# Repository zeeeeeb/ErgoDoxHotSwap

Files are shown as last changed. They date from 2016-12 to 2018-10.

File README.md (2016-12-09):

# Information
This repo is for the ErgoDox Mechanical Keyboard pcb and Litster's acrylic case designs (both standard and full hand).

## Changelog: 
2016-12-01: Updated with fixes to include proper support for 1u keys in the outer columns. Silkscreen updated to reflect ErgoDox.io as the new home of the ErgoDox. Removed unnessicary .hex files and teensy.dmg files. 

**See our [Releases](https://github.com/Ergodox-io/ErgoDox/releases) for details**

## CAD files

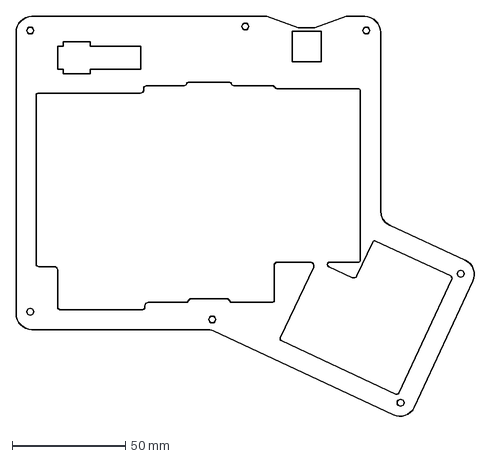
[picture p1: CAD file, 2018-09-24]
ErgoDox Acrylic Case/ErgoDOX Acrylic Case - Designed by Litster/Standard/Left/ErgoDOX Case Layer 2 Spacer - Left.dxf
202.8 x 177.8 mm

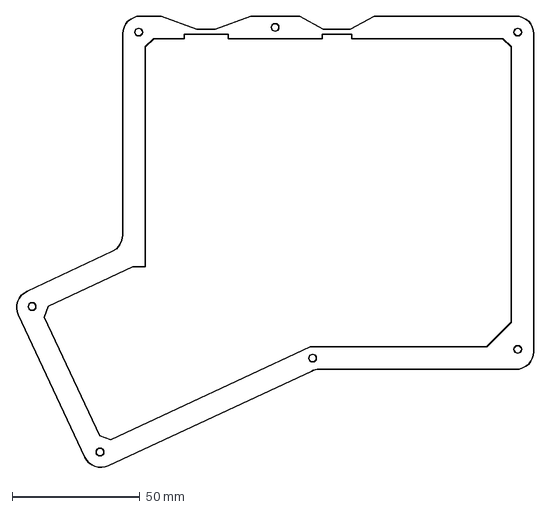
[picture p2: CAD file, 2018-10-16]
ErgoDox Acrylic Case/ErgoDOX Acrylic Case - Designed by Litster/Standard/Right/ErgoDOX Case Layer 4 Spacer - Right.dxf
202.8 x 177.8 mm

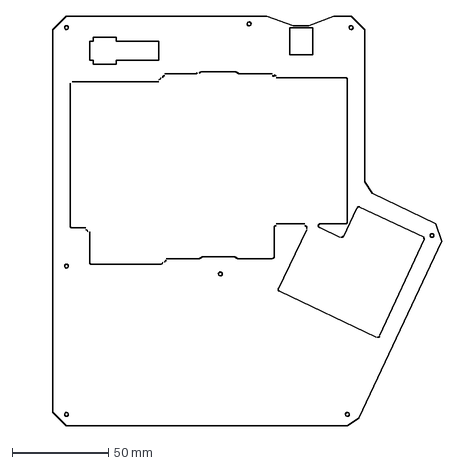
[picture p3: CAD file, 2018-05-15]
ErgoDox Acrylic Case/ErgoDOX Acrylic Case - Designed by Litster/with Wrist Rest/Left/ErgoDOX Case Layer 2 Spacer - Left.dxf
221.0 x 213.0 mm

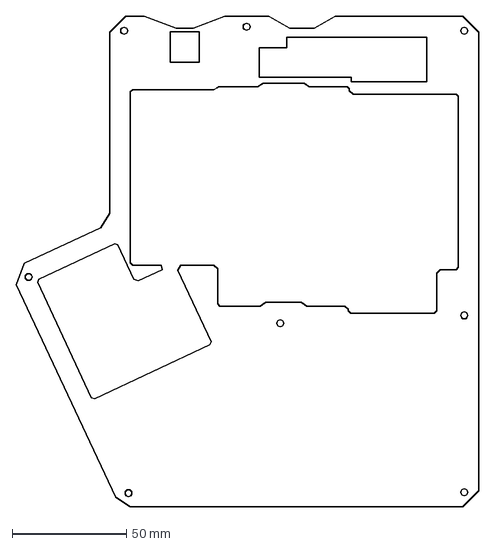
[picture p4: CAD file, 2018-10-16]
ErgoDox Acrylic Case/ErgoDOX Acrylic Case - Designed by Litster/with Wrist Rest/Right/ErgoDOX Wrist Rest Case Layer 2 Spacer - Right.dxf
202.0 x 214.1 mm

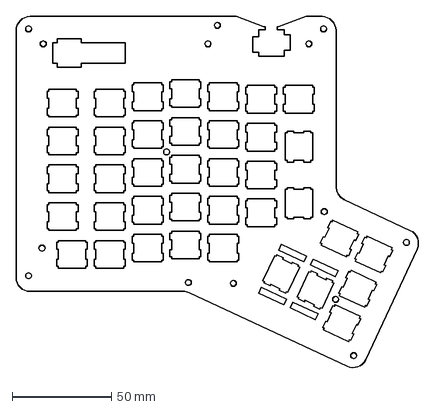
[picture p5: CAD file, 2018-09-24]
ErgoDox Acrylic Case/ErgoDOX Acrylic Case - Designed by Litster/Standard/Left/ErgoDOX Case Layer 3 Plate - Left.dxf
202.8 x 177.8 mm

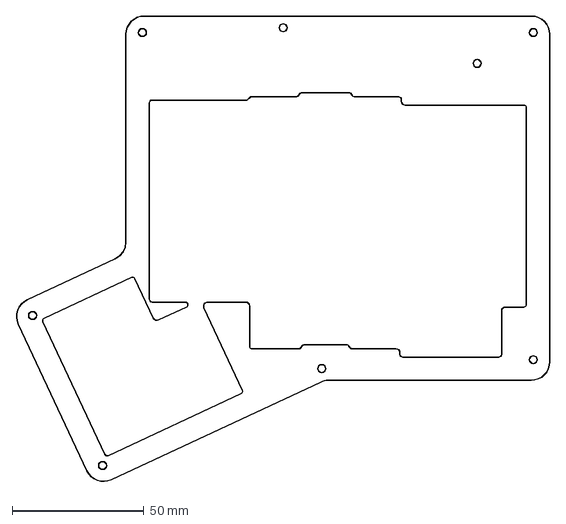
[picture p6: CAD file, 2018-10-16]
ErgoDox Acrylic Case/ErgoDOX Acrylic Case - Designed by Litster/Standard/Right/ErgoDOX Case Layer 1 Top - Right.dxf
202.8 x 177.8 mm

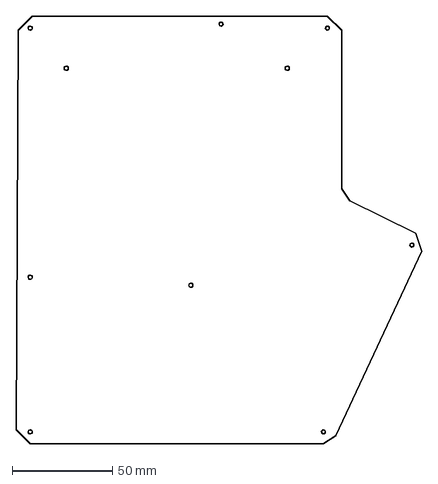
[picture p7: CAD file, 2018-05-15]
ErgoDox Acrylic Case/ErgoDOX Acrylic Case - Designed by Litster/with Wrist Rest/Left/ErgoDOX Case Layer 5 Bottom - Left.dxf
202.0 x 213.0 mm

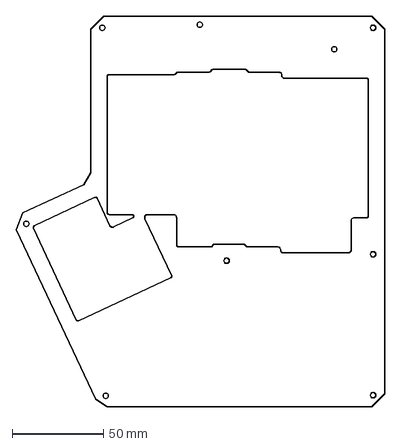
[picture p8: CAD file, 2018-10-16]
ErgoDox Acrylic Case/ErgoDOX Acrylic Case - Designed by Litster/with Wrist Rest/Right/ErgoDOX Wrist Rest Case Layer 1 Top - Right.dxf
202.0 x 214.1 mm

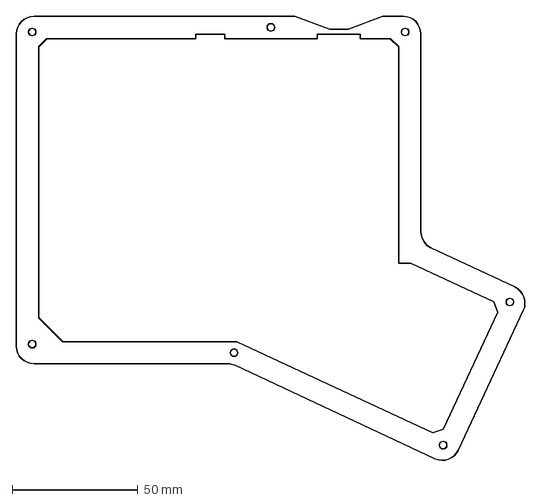
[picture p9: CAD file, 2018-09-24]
ErgoDox Acrylic Case/ErgoDOX Acrylic Case - Designed by Litster/Standard/Left/ErgoDOX Case Layer 4 Spacer - Left.dxf
202.8 x 177.8 mm

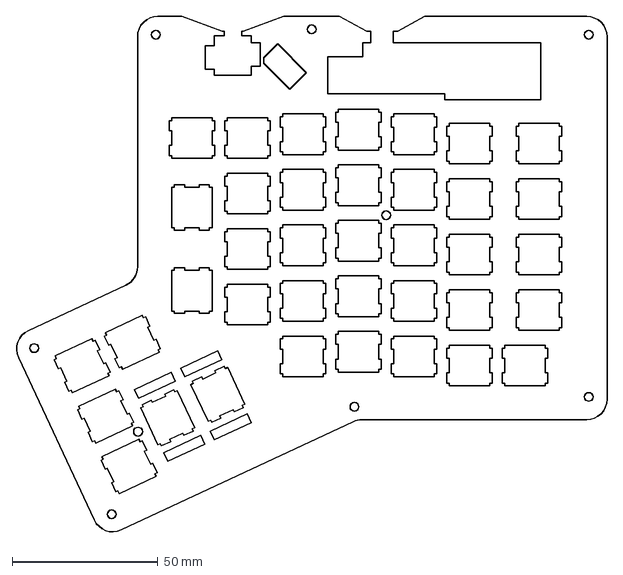
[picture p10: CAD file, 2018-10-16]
ErgoDox Acrylic Case/ErgoDOX Acrylic Case - Designed by Litster/Standard/Right/ErgoDOX Case Layer 3 Plate - Right.dxf
202.8 x 177.8 mm

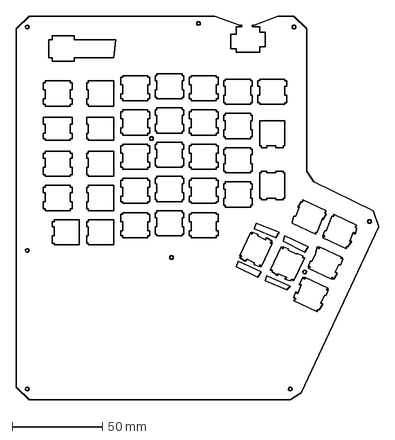
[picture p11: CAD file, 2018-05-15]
ErgoDox Acrylic Case/ErgoDOX Acrylic Case - Designed by Litster/with Wrist Rest/Left/ErgoDOX Case Layer 3 Plate - Left.dxf
201.0 x 213.0 mm

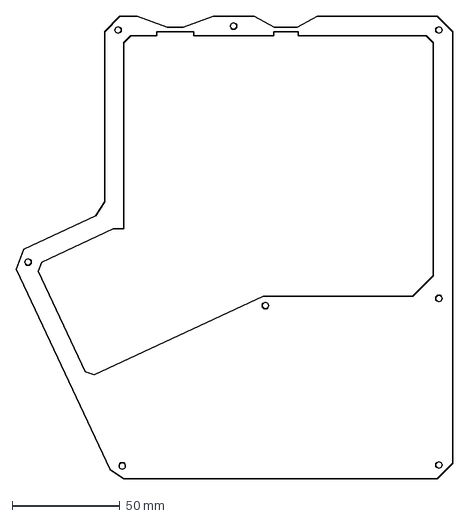
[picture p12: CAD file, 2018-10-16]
ErgoDox Acrylic Case/ErgoDOX Acrylic Case - Designed by Litster/with Wrist Rest/Right/ErgoDOX Wrist Rest Case Layer 4 Spacer - Right.dxf
202.0 x 214.1 mm

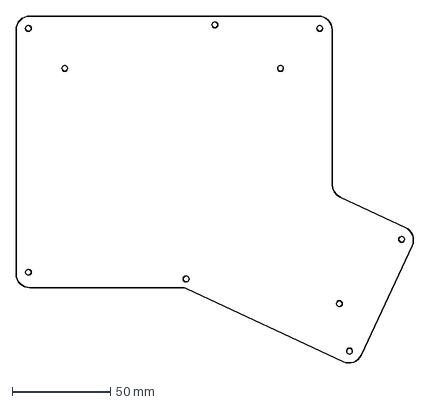
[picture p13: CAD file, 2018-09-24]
ErgoDox Acrylic Case/ErgoDOX Acrylic Case - Designed by Litster/Standard/Left/ErgoDOX Case Layer 5 Bottom - Left.dxf
202.8 x 177.8 mm

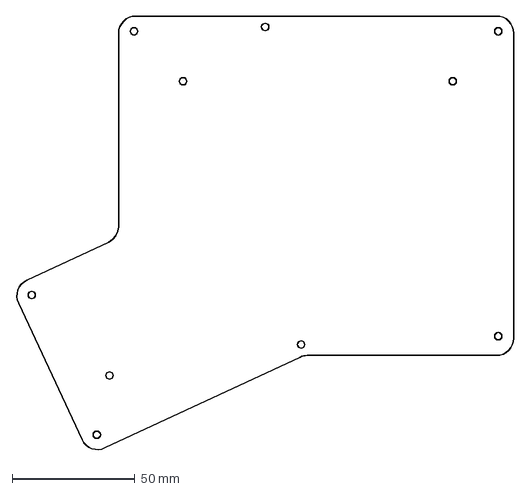
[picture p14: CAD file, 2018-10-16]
ErgoDox Acrylic Case/ErgoDOX Acrylic Case - Designed by Litster/Standard/Right/ErgoDOX Case Layer 5 Bottom - Right.dxf
202.8 x 177.8 mm

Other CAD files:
ErgoDox Acrylic Case/ErgoDOX Acrylic Case - Designed by Litster/with Wrist Rest/Left/ErgoDOX Case Layer 1 Top - Left.dxf
ErgoDox Acrylic Case/ErgoDOX Acrylic Case - Designed by Litster/with Wrist Rest/Right/ErgoDOX Wrist Rest Case Layer 3 Plate - Right.dxf
ErgoDox Acrylic Case/ErgoDOX Acrylic Case - Designed by Litster/Standard/Left/ErgoDOX Case Layer 1 Top - Left.dxf
ErgoDox Acrylic Case/ErgoDOX Acrylic Case - Designed by Litster/Standard/Right/ErgoDOX Case Layer 2 Spacer - Right.dxf
ErgoDox Acrylic Case/ErgoDOX Acrylic Case - Designed by Litster/with Wrist Rest/Left/ErgoDOX Case Layer 4 Spacer - Left.dxf
ErgoDox Acrylic Case/ErgoDOX Acrylic Case - Designed by Litster/with Wrist Rest/Right/ErgoDOX Wrist Rest Case Layer 5 Bottom - Right.dxf

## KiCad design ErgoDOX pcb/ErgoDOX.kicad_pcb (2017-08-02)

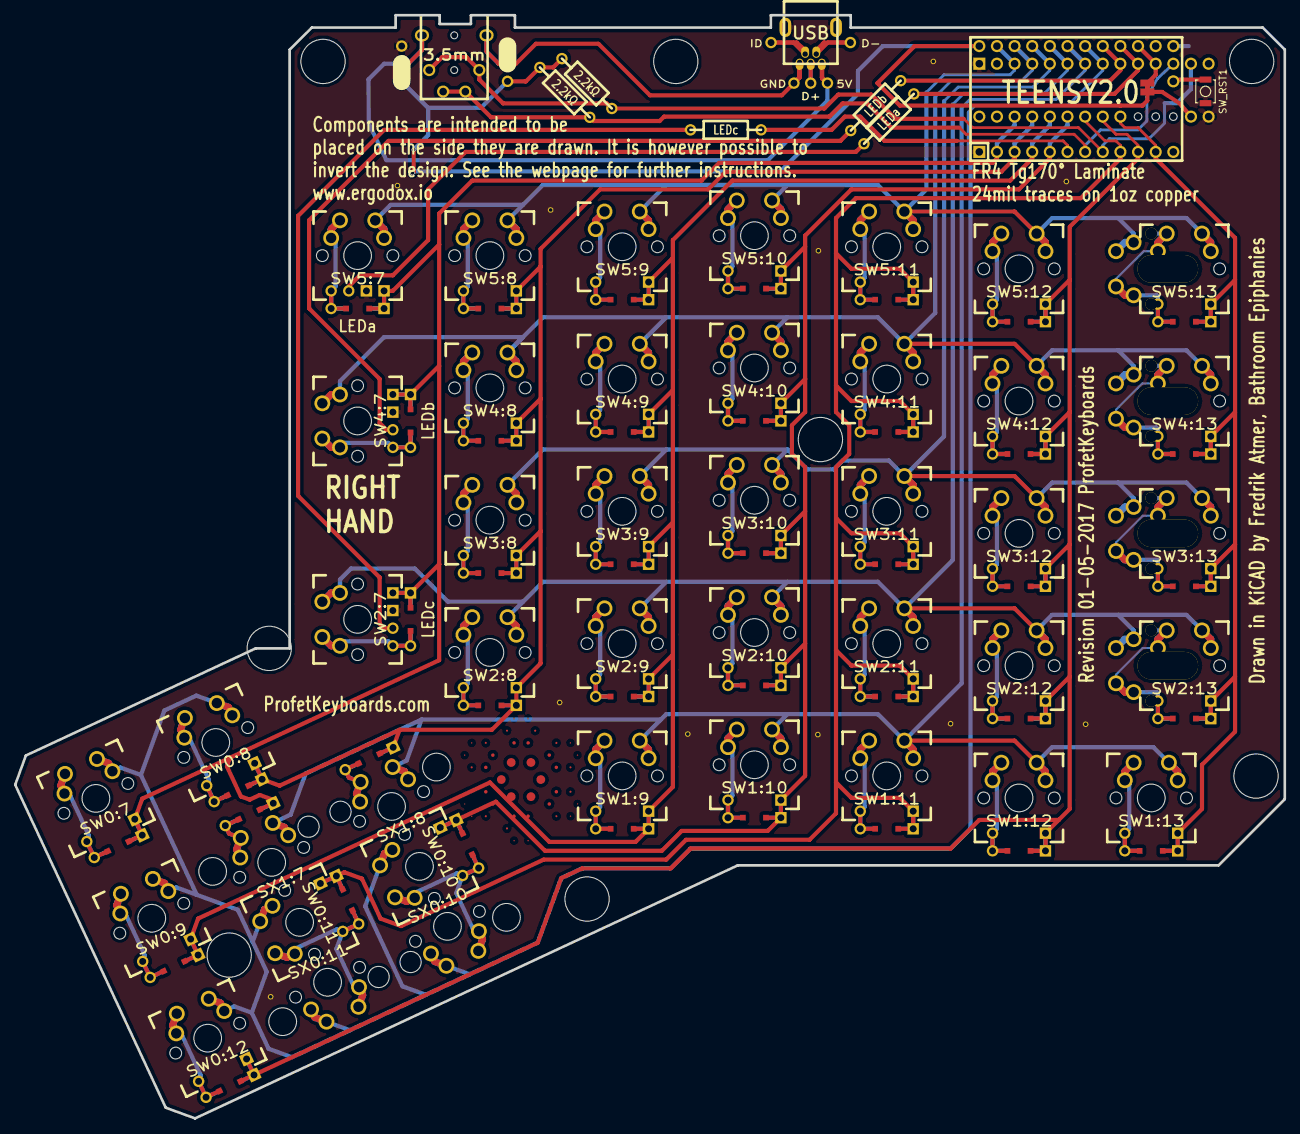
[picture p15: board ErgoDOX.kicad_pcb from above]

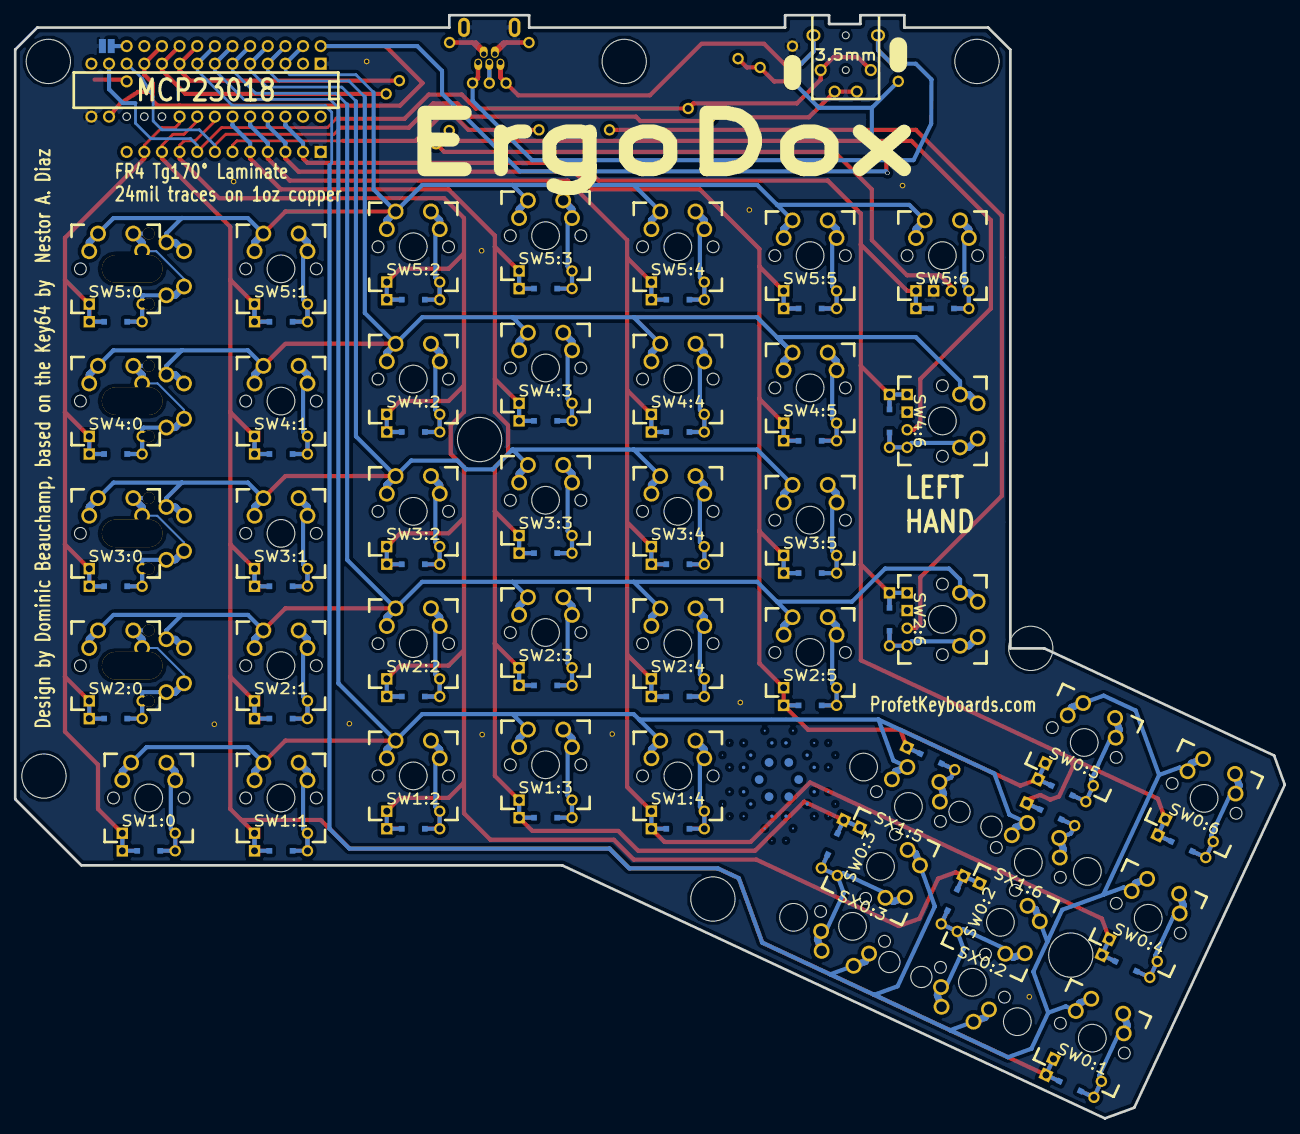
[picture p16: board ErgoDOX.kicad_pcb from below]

Board: 2 copper layers, 182.8 x 158.9 mm, 77 parts (4 on the bottom side), 66 nets.

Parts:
D1:7, D1:8: D; DIODE
H99: MECHANICAL; ErgoDOXmech
J1: USB; USBMINImod
J2: 3.5mm; 4pin35mmAudio
J3, J4: JMP; 100PITCH1X3
JP1, JP2: JUMPER; GAP
LED_A1: LEDa; MX_LED
LED_B1: LEDb; MX_LED
LED_C1: LEDc; MX_LED
R1, R2: 2.2kΩ; RESISTOR
RA1: LEDa; RESISTOR
RB1: LEDb; RESISTOR
RC1: LEDc; RESISTOR
S1, S2: STAB200; STAB_PCB940
STAR_1: STAR_FRONT; STAR
STAR_2: STAR_BACK; STAR
STITCHING_VIA: STITCHING_VIA
STITCHING_VIA#2, STITCHING_VIA#3, STITCHING_VIA#4, STITCHING_VIA#5, STITCHING_VIA#6, STITCHING_VIA#7, STITCHING_VIA#8, STITCHING_VIA#9, STITCHING_VIA#10, STITCHING_VIA#11: STITCHING_VIA
SW0:7: SW0:6; MX_FLIP_DIODE
SW0:8: SW0:5; MX_FLIP_DIODE
SW0:9: SW0:4; MX_FLIP_DIODE
SW0:10: SW0:3; MX_FLIP_DIODE
SW0:11: SW0:2; MX_FLIP_DIODE
SW0:12: SW0:1; MX_FLIP_DIODE
SW1:9: SW1:4; MX_FLIP_DIODE
SW1:10: SW1:3; MX_FLIP_DIODE
SW1:11: SW1:2; MX_FLIP_DIODE
SW1:12: SW1:1; MX_FLIP_DIODE
SW1:13: SW1:0; MX_FLIP_DIODE
SW2:7: SW2:6; MX_FLIP_DIODE
SW2:8: SW2:5; MX_FLIP_DIODE
SW2:9: SW2:4; MX_FLIP_DIODE
SW2:10: SW2:3; MX_FLIP_DIODE
SW2:11: SW2:2; MX_FLIP_DIODE
SW2:12: SW2:1; MX_FLIP_DIODE
SW2:13: SW2:0; MX_FLIP_XX
SW3:8: SW3:5; MX_FLIP_DIODE
SW3:9: SW3:4; MX_FLIP_DIODE
SW3:10: SW3:3; MX_FLIP_DIODE
SW3:11: SW3:2; MX_FLIP_DIODE
SW3:12: SW3:1; MX_FLIP_DIODE
SW3:13: SW3:0; MX_FLIP_XX
SW4:7: SW4:6; MX_FLIP_DIODE
SW4:8: SW4:5; MX_FLIP_DIODE
SW4:9: SW4:4; MX_FLIP_DIODE
SW4:10: SW4:3; MX_FLIP_DIODE
SW4:11: SW4:2; MX_FLIP_DIODE
SW4:12: SW4:1; MX_FLIP_DIODE
SW4:13: SW4:0; MX_FLIP_XX
SW5:7: SW5:6; MX_FLIP_DIODE
SW5:8: SW5:5; MX_FLIP_DIODE
SW5:9: SW5:4; MX_FLIP_DIODE
SW5:10: SW5:3; MX_FLIP_DIODE
SW5:11: SW5:2; MX_FLIP_DIODE
SW5:12: SW5:1; MX_FLIP_DIODE
SW5:13: SW5:0; MX_FLIP_XX
SW_RST1: SWITCH_PUSH; SW_SPST_B3U-1000P
SX0:10: SX0:3; MX_FLIP
SX0:11: SX0:2; MX_FLIP
SX1:7: SX1:6; MX_FLIP
SX1:8: SX1:5; MX_FLIP
U1: TEENSY2.0; TEENSY_2.0_WITH_RESET
U2: MCP23018; DIP28_300

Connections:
/COL0: SW1:13.4, SW2:13.4, SW3:13.4, SW4:13.4, SW5:13.4, U1.11, U2.20
/COL1: SW0:12.4, SW1:12.4, SW2:12.4, SW3:12.4, SW4:12.4, SW5:12.4, U1.10, U2.21
/COL4: SW0:9.4, SW1:9.4, SW2:9.4, SW3:9.4, SW4:9.4, SW5:9.4, U1.4, U2.24
/COL5: D1:8.2, SW0:8.4, SW2:8.4, SW3:8.4, SW4:8.4, SW5:8.4, U1.3, U2.25
/COL6: D1:7.2, SW0:7.4, SW2:7.4, SW4:7.4, SW5:7.4, U1.2, U2.26
/COL10: SW0:10.4, SW1:10.4, SW2:10.4, SW3:10.4, SW4:10.4, SW5:10.4, U1.5, U2.23
/COL11: SW0:11.4, SW1:11.4, SW2:11.4, SW3:11.4, SW4:11.4, SW5:11.4, U1.9, U2.22
/LED_A: RA1.1, U1.21, U2.10
/LED_B: RB1.1, U1.22, U2.9
/LED_C: RC1.1, U1.6
/ROW0: SW0:7.1, SW0:8.1, SW0:9.1, SW0:10.1, SW0:11.1, SW0:12.1, SX0:10.1, SX0:11.1, U1.23, U2.8
/ROW1: SW1:9.1, SW1:10.1, SW1:11.1, SW1:12.1, SW1:13.1, SX1:7.1, SX1:8.1, U1.24, U2.7
/ROW2: SW2:7.1, SW2:8.1, SW2:9.1, SW2:10.1, SW2:11.1, SW2:12.1, SW2:13.1, U1.25, U2.6
/ROW3: SW3:8.1, SW3:9.1, SW3:10.1, SW3:11.1, SW3:12.1, SW3:13.1, U1.26, U2.5
/ROW4: SW4:7.1, SW4:8.1, SW4:9.1, SW4:10.1, SW4:11.1, SW4:12.1, SW4:13.1, U1.27, U2.4
/ROW5: SW5:7.1, SW5:8.1, SW5:9.1, SW5:10.1, SW5:11.1, SW5:12.1, SW5:13.1, U1.28, U2.3
/RST: SW_RST1.1, U1.16
/SCLM: J2.3, J2.5, R2.2, U1.7, U2.12
/SDAM: J2.2, J2.6, R1.2, U1.8, U2.13
GND: J1.6, J3.3, J4.3, JP2.1, LED_A1.2, LED_B1.2, LED_C1.2, STITCHING_VIA.GND, STITCHING_VIA#2.GND, STITCHING_VIA#3.GND, STITCHING_VIA#4.GND, STITCHING_VIA#5.GND, STITCHING_VIA#6.GND, STITCHING_VIA#7.GND, STITCHING_VIA#8.GND, STITCHING_VIA#9.GND, STITCHING_VIA#10.GND, STITCHING_VIA#11.GND, SW_RST1.2, U1.1, U1.18, U2.1, U2.15
unnamed: D1:7.1, SX1:7.2
unnamed: D1:8.1, SX1:8.2
unnamed: J1.1, J2.4, J4.2
unnamed: J1.5, J2.1, J3.2
unnamed: LED_A1.1, RA1.2
unnamed: LED_B1.1, RB1.2
unnamed: LED_C1.1, RC1.2
unnamed: SW0:7.2, SW0:7.3
unnamed: SW0:8.2, SW0:8.3
unnamed: SW0:9.2, SW0:9.3
unnamed: SW0:10.2, SW0:10.3, SX0:10.2
unnamed: SW0:11.2, SW0:11.3, SX0:11.2
unnamed: SW0:12.2, SW0:12.3
unnamed: SW1:9.2, SW1:9.3
unnamed: SW1:10.2, SW1:10.3
unnamed: SW1:11.2, SW1:11.3
unnamed: SW1:12.2, SW1:12.3
unnamed: SW1:13.2, SW1:13.3
unnamed: SW2:7.2, SW2:7.3
unnamed: SW2:8.2, SW2:8.3
unnamed: SW2:9.2, SW2:9.3
unnamed: SW2:10.2, SW2:10.3
unnamed: SW2:11.2, SW2:11.3
unnamed: SW2:12.2, SW2:12.3
unnamed: SW2:13.2, SW2:13.3
unnamed: SW3:8.2, SW3:8.3
unnamed: SW3:9.2, SW3:9.3
unnamed: SW3:10.2, SW3:10.3
unnamed: SW3:11.2, SW3:11.3
unnamed: SW3:12.2, SW3:12.3
unnamed: SW3:13.2, SW3:13.3
unnamed: SW4:7.2, SW4:7.3
unnamed: SW4:8.2, SW4:8.3
unnamed: SW4:9.2, SW4:9.3
unnamed: SW4:10.2, SW4:10.3
unnamed: SW4:11.2, SW4:11.3
unnamed: SW4:12.2, SW4:12.3
unnamed: SW4:13.2, SW4:13.3
unnamed: SW5:7.2, SW5:7.3
unnamed: SW5:8.2, SW5:8.3
unnamed: SW5:9.2, SW5:9.3
unnamed: SW5:10.2, SW5:10.3
unnamed: SW5:11.2, SW5:11.3
unnamed: SW5:12.2, SW5:12.3
unnamed: SW5:13.2, SW5:13.3
VCC: J3.1, J4.1, JP1.1, R1.1, R2.1, U1.20, U1.29, U2.11, U2.16

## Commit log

2017-01-06 Adding support for reversible female USB Port and optional reset switch. This will allow the right hand of the Ergodox to be flipped and used as the left hand. In this scenario the teensy should be s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
    Reset switch part number: OMRON B3U-1000P
    [ErgoDOX-B.Mask.gbs, ErgoDOX-B.Paste.gbp, ErgoDOX-B.SilkS.gbo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]
2018-01-28 Fixing all loops in all dxf files
    Almost all DXF files had some loops in it (lines or dots that were not connected to anything else). That was a problem, as most laser cutter will act weirdly because of that.
    Fixing this allow laser cutter to do the cut in one smooth line, and not try to leave some very close gaps because some dots were not connected.
    Files were imported then exported using Fusion 360. It seems that they have been vastly re-written, but as the DXF format has been invented by Autodesk, it should be ok and readable by other CAD softwares.
    You can see an example of the loops in one file here : https://imgur.com/zZA2Odz
    This is checked using an addin called Sketch Checker in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
    [ErgoDOX Case Layer 1 Top - Left.dxf, ErgoDOX Case Layer 1 Top - Right.dxf, ErgoDOX Case Layer 2 Spacer - Left.dxf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]
2018-09-24 [case] Fix right hand size
    Right hand was 10 times bigger than left hand.
    Also replaces commas by dots as decimal separator.
    [ErgoDOX Case Layer 1 Top - Left.dxf, ErgoDOX Case Layer 1 Top - Right.dxf, ErgoDOX Case Layer 2 Spacer - Left.dxf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]
2018-10-13 [case] Fix right hand scale
    [ErgoDOX Case Layer 1 Top - Right.dxf, ErgoDOX Case Layer 2 Spacer - Right.dxf, ErgoDOX Case Layer 3 Plate - Right.dxf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]
